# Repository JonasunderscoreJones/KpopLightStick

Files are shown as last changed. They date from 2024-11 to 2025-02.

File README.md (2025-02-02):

# K-Pop Lightstick
This Repo features the software of an Arduino Lightstick as well as the 3D Files for a custom **NCT DREAM** Lightstick

<div style="display: flex; justify-content: space-between">
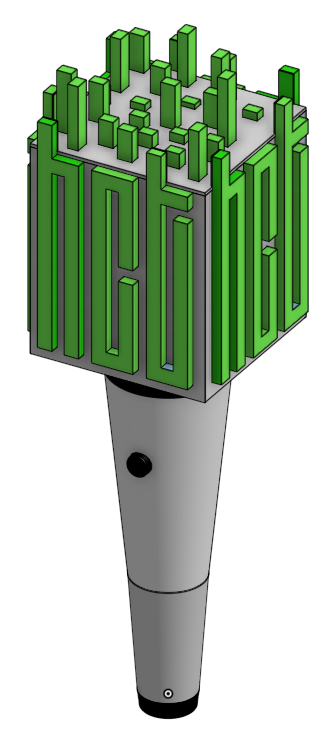
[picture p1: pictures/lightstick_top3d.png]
  
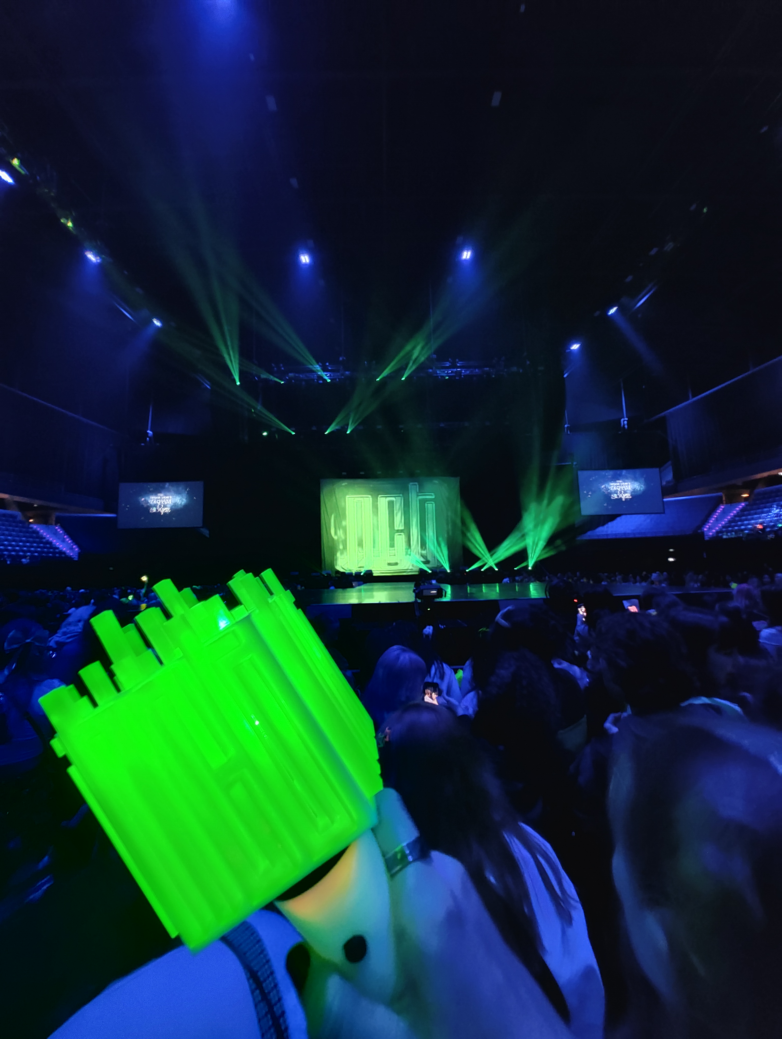
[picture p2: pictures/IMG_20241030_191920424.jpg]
  
</div>

## 3D-Print
The Lightstick was printed in 3 different colors.

The `Block Top.stl` file can be modified to not come with holes for the `Neo_City.stl` cubes rising out of the top to match the official lightstick more accurately.

*Be aware, that this 3D Build is slightly larger than the Official NCT DREAM Lightstick and you may not be allowed into concerts with it. I had no issues at the NCT DREAM Tour 2024 in Rotterdam but the security checks at the entrance were cursory, lacking the thoroughness you would usually have at different concerts.*

**WHITE:**
- `Block Base.stl`
- `Block Side.stl`
- `Block Top.stl`
- `Handle Base Bottom.stl`
- `Handle Base.stl`

**BLACK:**
- `Handle Ring Bottom`
- `Handle Ring Top`
- `Power Button`

**TRANSPARENT NEON GREEN:**
- `Neo_City.stl`
- `shiny_c_thicker.stl`
- `shiny_c.stl`
- `shiny_n_thicker.stl`
- `shiny_n.stl`
- `shiny_t_thicker.stl`
- `shiny_t.stl`

*Since I had issues with the prints of the letters, I made a thicker version of each letter to ensure that there would be no holes.*

## Assembly
The Assembly of the Prints is pretty self-explanatory. Take a look at the pictures in the `/picture` folder of the repo.

I chose to not glue the `Block Base.stl` and the `Handle Base.stl` pieces together to be able to troubleshoot/replace the electronics inside at any time.

## Electronics
The `arduino.ino` file contains the Arduino code I used for the lightstick.

An **Arduino Nano** was used with the following Pin-Out:
```cpp
const int buttonPin = 2; // Pin for the button
const int redPin = 11; // Pin for the red channel of RGB LED
const int greenPin = 10; // Pin for the green channel of RGB LED
const int bluePin = 9; // Pin for the blue channel of RGB LED
const int motorPin = 8; // Pin to control the motor
```
*Note: These are the Digital Pins on the Arduino Nano*

### Features of the Program
- The `buttonPin` is for the Power Button on the `Handle Base.stl` and is used for controlling the Light.
- The `redPin`, `greenPin` and `bluePin` are used for controlling the LED. IMPORTANT: These are **ANODE RGB LEDs**. If You plan on using *Kathode LEDs*, simply remove `255 - ` from the `setRGB` function at the bottom of the Program, to invert the values. (This is only a fix based on logic, I have no LEDs to test it)
- The `motorPin` is used for controlling a simple Vibration Motor that runs for 1 second when turning on the Lightstick. This is inspired from the *VIXX Official Lightstick* that has similar behaviour. It is completely irrelevant to the general functionality of the Lightstick which is, well, to have Light.

### Instructions
1. Connect a Power button to the Arduino `buttonPin` and groud
2. Connect the Vibration Motor (A simple motor with some weight glued off-axis to make it vibrate when rotating) to the `motorPin` and ground
3. Connect the RGB LEDs to the 3 color pins and 3.3V
4. Glue together 3 AAA Batteries, solder them together and connect them to the Voltage In` and ground
5. Flash the Arduino Nano with the program and you're done.
6. Insert the electronics into the Arduino and close it up. The batteries go into the `Handle Base Bottom.stl` that is simply forced into the `Handle Base.stl`. There is a locking mechanism like the Official Lightstick has but I have found it to not be necessary as the fit is tight enough.

## Usage
Hold the Power Button for approx. 1 second and release it. The Lightstick should vibrate for a second and then the lights turn on, defaulting to a neon green.

Press the button to cycle between colors and hold it for a second to turn it off again.

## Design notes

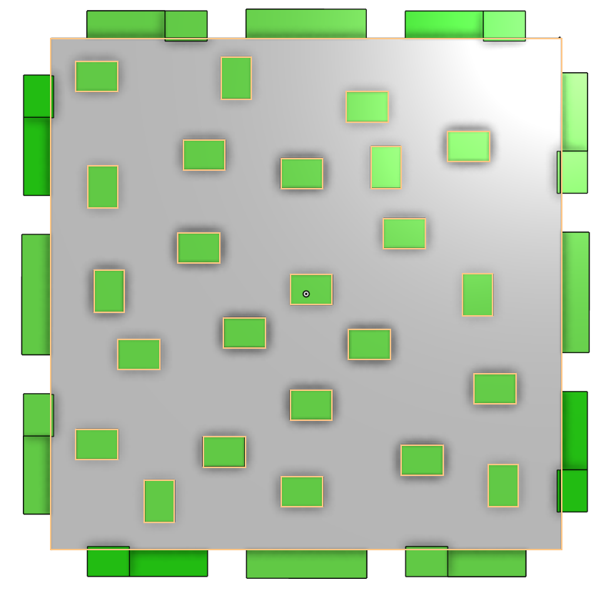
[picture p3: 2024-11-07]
pictures/lightstick_top.png

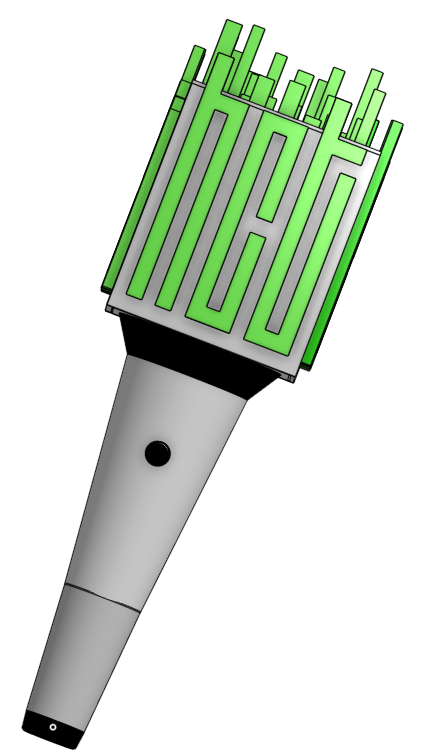
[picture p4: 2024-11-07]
pictures/lightstick_diagonal.png

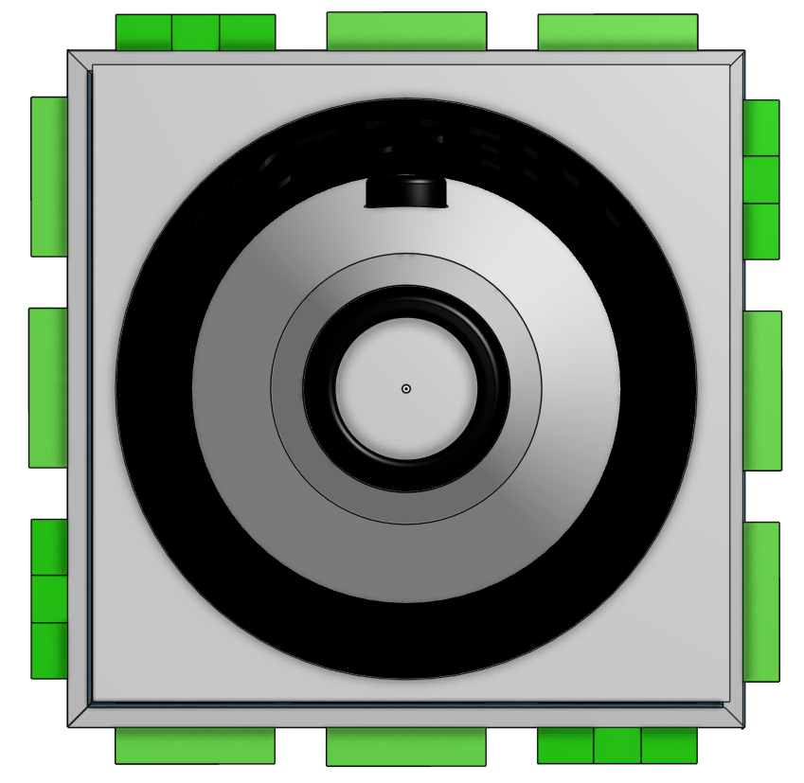
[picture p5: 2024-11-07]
pictures/lightstick_bottom.png

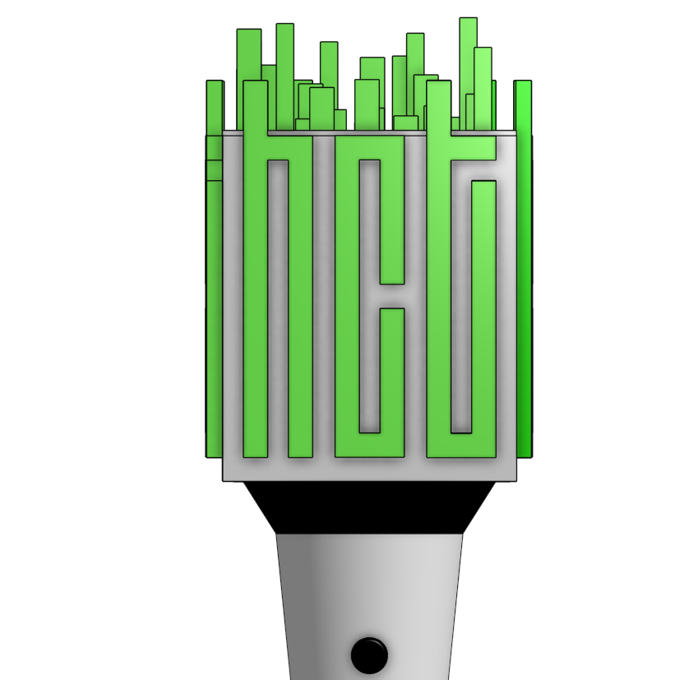
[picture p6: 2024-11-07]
pictures/lightstick_cube.png

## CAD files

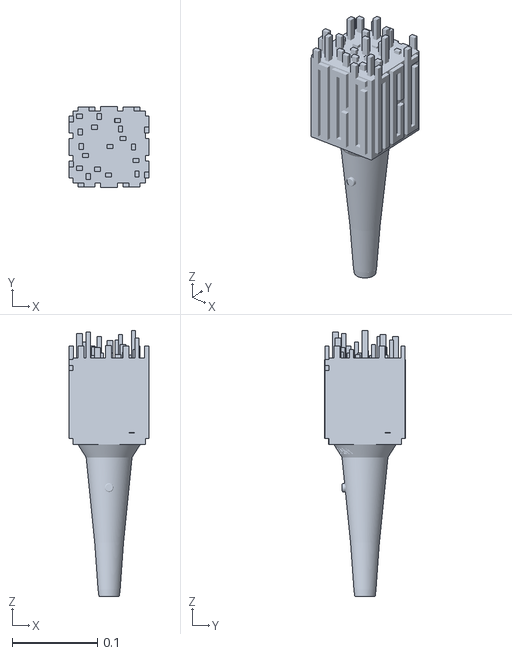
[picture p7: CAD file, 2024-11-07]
3d-files/assembly_complete.stl
0.0945 x 0.0946 x 0.313

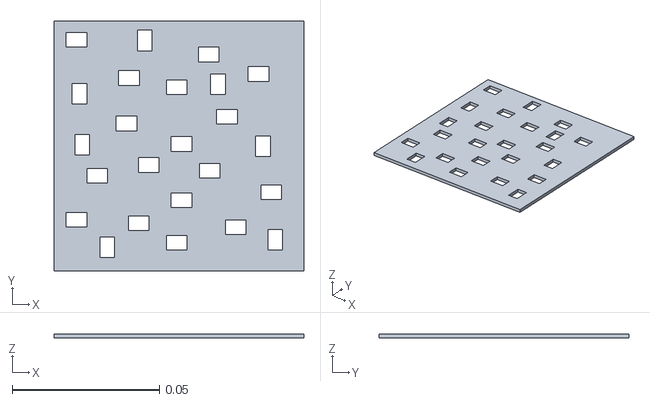
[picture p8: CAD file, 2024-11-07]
3d-files/Block Top.stl
0.085 x 0.085 x 0.0015

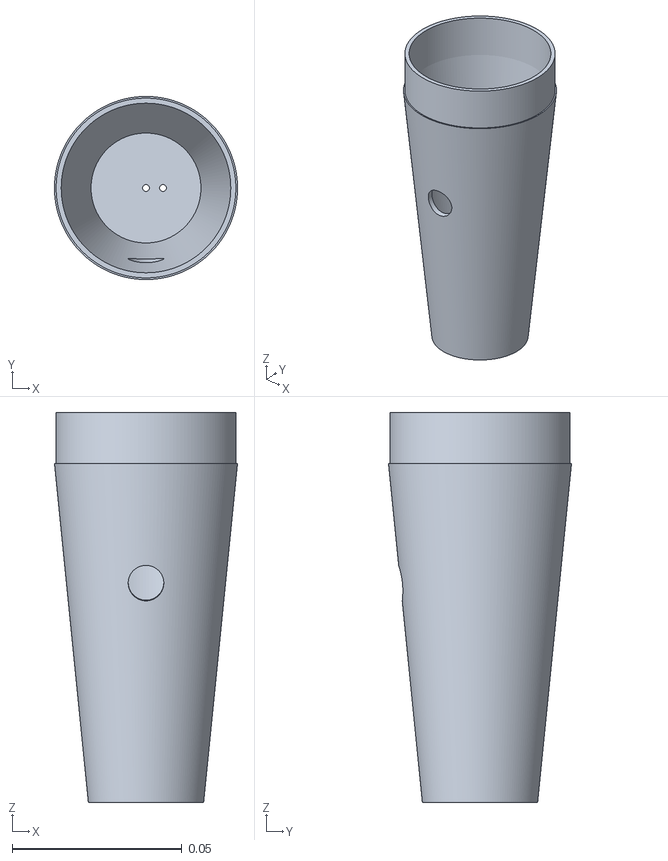
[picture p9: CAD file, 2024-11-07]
3d-files/Handle Base.stl
0.054 x 0.054 x 0.115

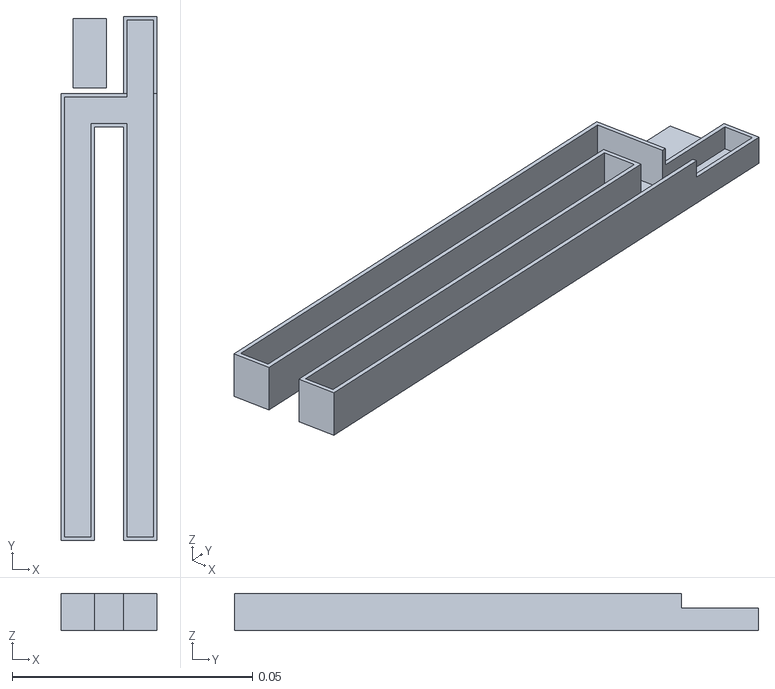
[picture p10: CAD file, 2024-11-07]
3d-files/shiny_n_thick.stl
0.02 x 0.109 x 0.00775

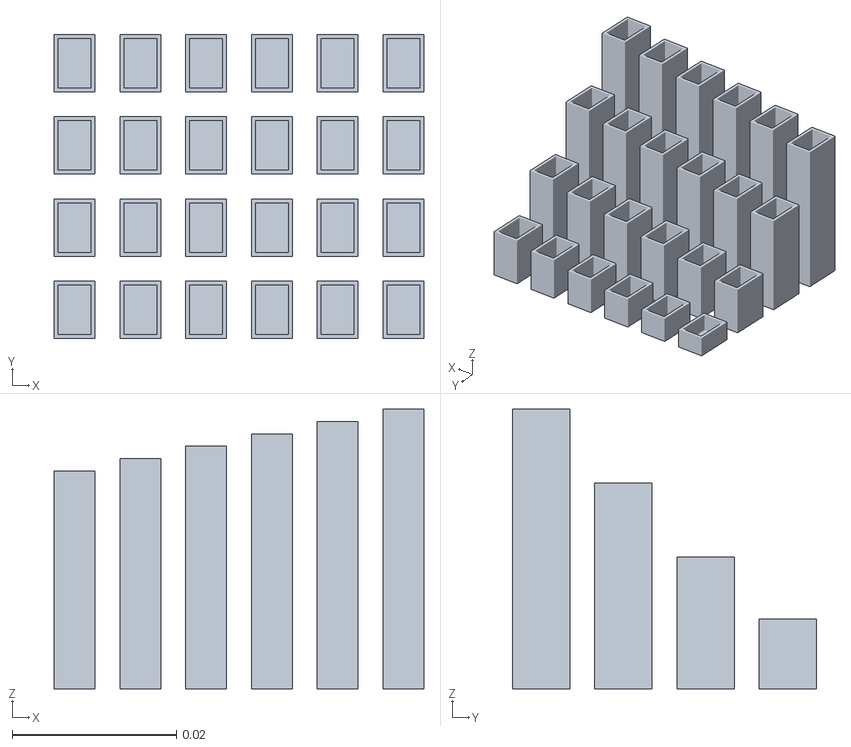
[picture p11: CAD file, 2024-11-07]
3d-files/Neo_City.stl
0.045 x 0.037 x 0.034

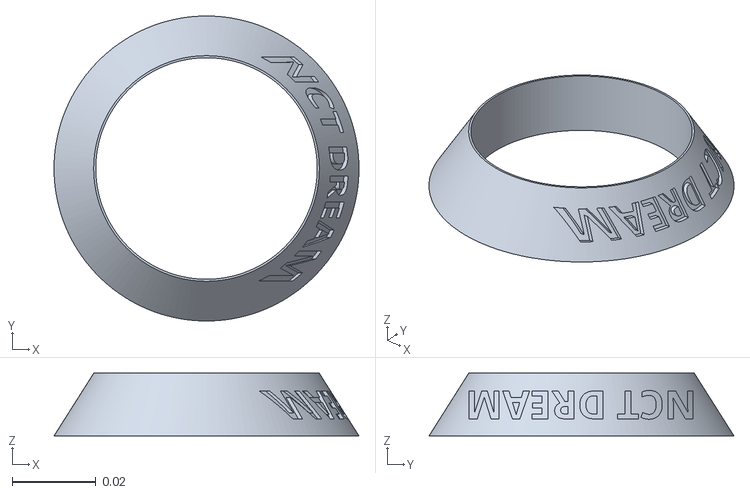
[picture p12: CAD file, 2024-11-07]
3d-files/Handle Ring Top.stl
0.073 x 0.073 x 0.015

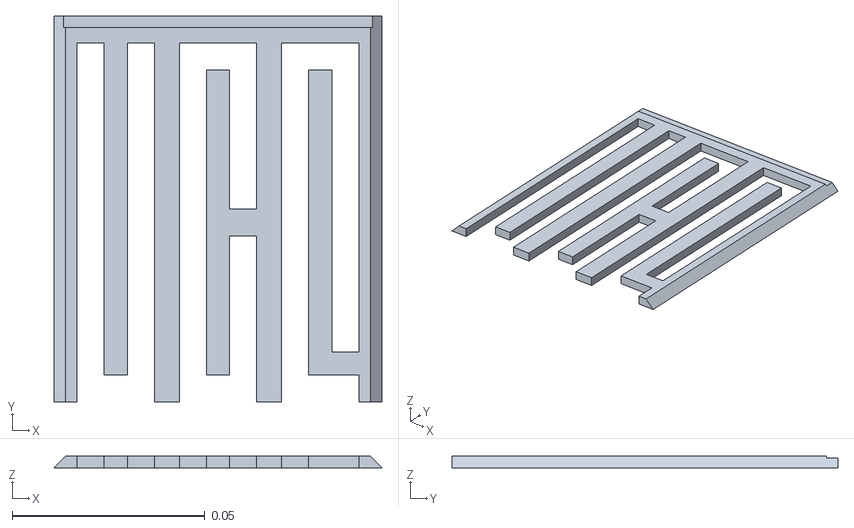
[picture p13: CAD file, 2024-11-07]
3d-files/Block Side.stl
0.085 x 0.1 x 0.003

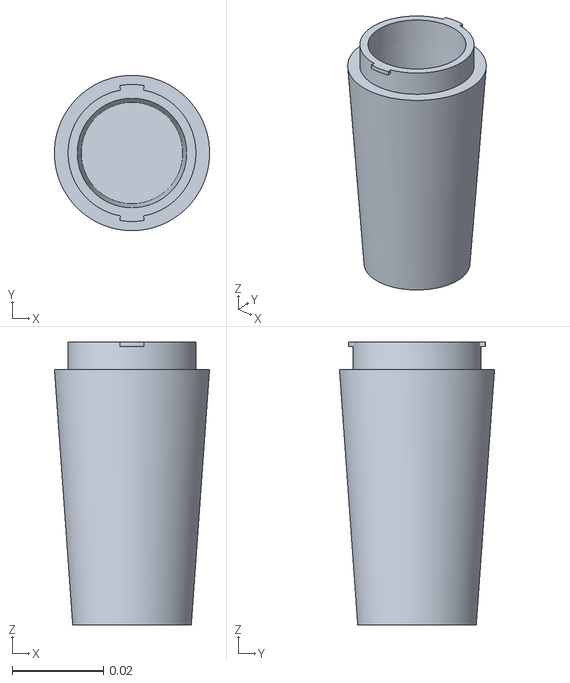
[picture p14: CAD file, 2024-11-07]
3d-files/Handle Base Bottom.stl
0.034 x 0.034 x 0.062

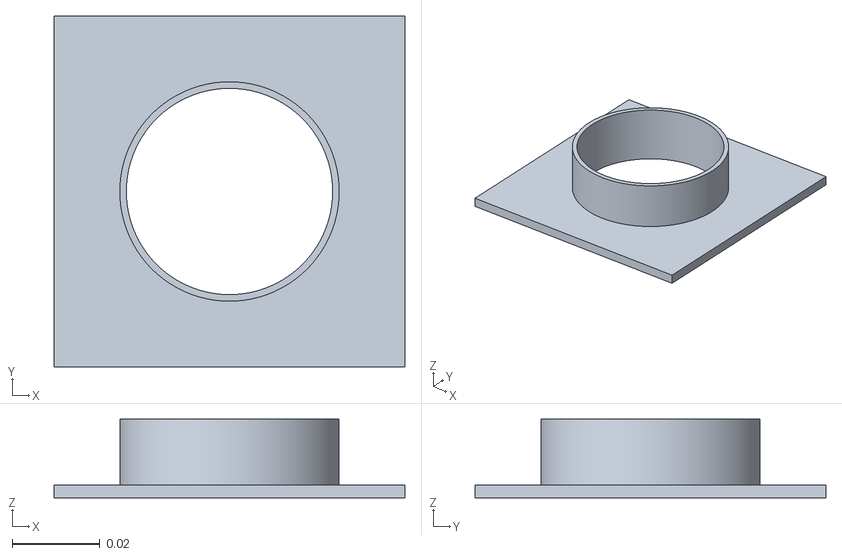
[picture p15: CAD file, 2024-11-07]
3d-files/Block Base.stl
0.08 x 0.08 x 0.018

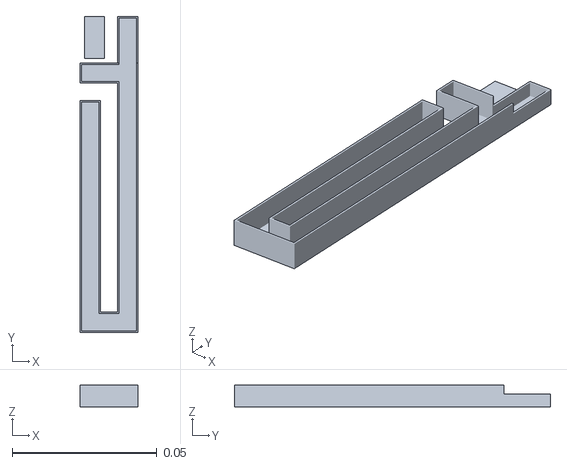
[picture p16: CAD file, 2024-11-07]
3d-files/shiny_t.stl
0.02 x 0.109 x 0.0075

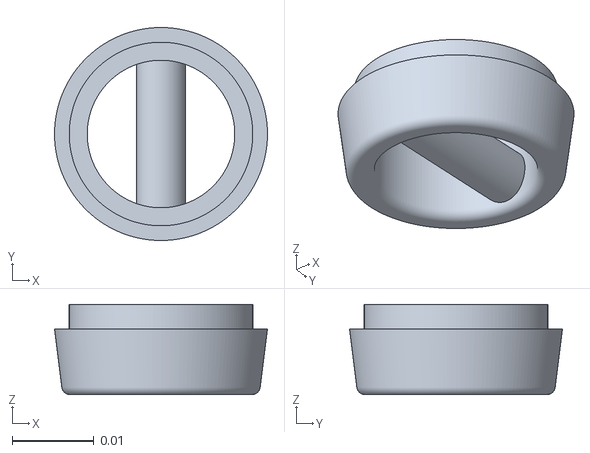
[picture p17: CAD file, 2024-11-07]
3d-files/Handle Ring Bottom.stl
0.026 x 0.026 x 0.011

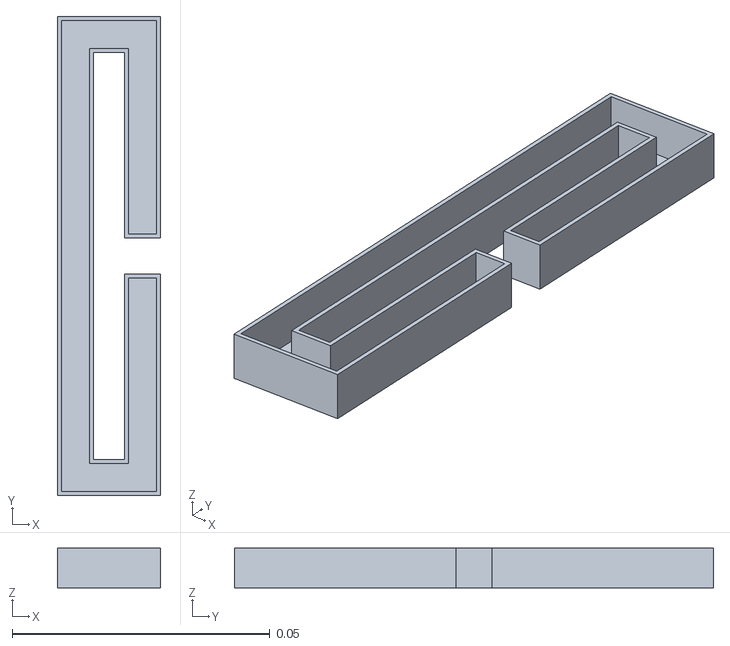
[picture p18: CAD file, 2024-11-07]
3d-files/shiny_c_thick.stl
0.02 x 0.093 x 0.00775

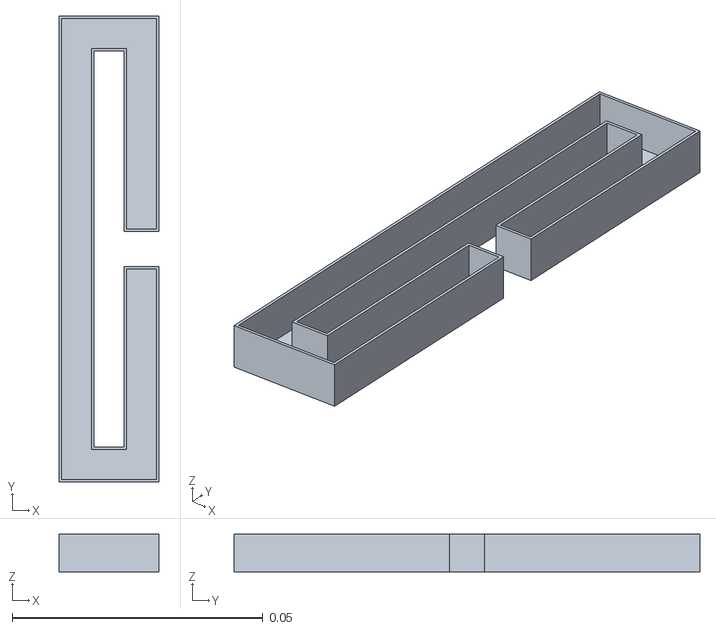
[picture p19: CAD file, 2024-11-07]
3d-files/shiny_c.stl
0.02 x 0.093 x 0.0075

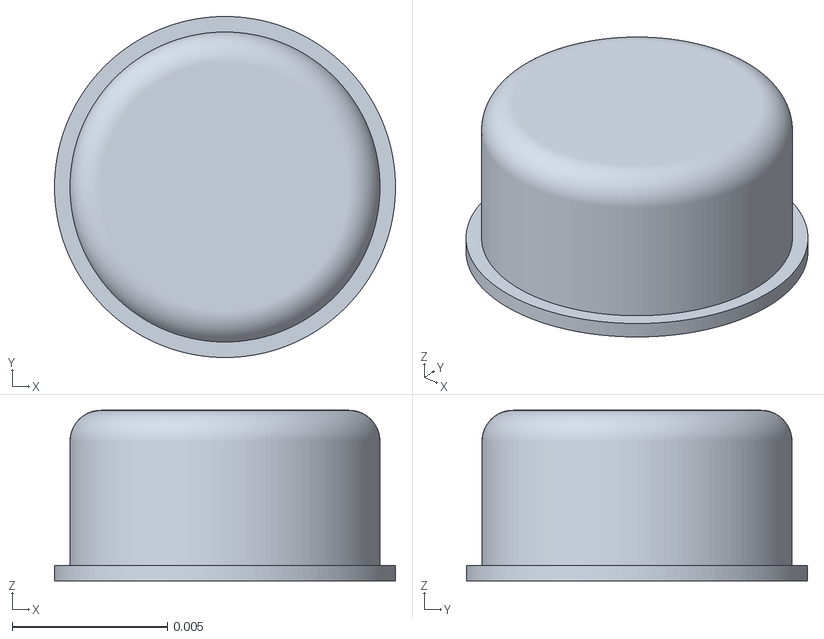
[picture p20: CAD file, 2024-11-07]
3d-files/Power Button.stl
0.011 x 0.011 x 0.0055

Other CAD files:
3d-files/shiny_t_thick.stl
3d-files/shiny_n.stl

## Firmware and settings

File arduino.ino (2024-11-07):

const int buttonPin = 2; // Pin for the button
const int redPin = 11; // Pin for the red channel of RGB LED
const int greenPin = 10; // Pin for the green channel of RGB LED
const int bluePin = 9; // Pin for the blue channel of RGB LED
const int motorPin = 8; // Pin to control the motor

bool ledState = false; // State of the onboard LED
unsigned long buttonPressStartTime = 0; // Time when the button press starts
bool buttonPressed = false; // Current button pressed state
unsigned long lastButtonPress = 0; // Last time the button was pressed
int colorIndex = 0; // Index for cycling colors

// Define colors to cycle through (RGB format)
const int colors[][3] = {
    {127,255,0},     // Neon Green
    {255, 0, 0},    // Red
    {0, 255, 0},    // Green
    {0, 0, 255},    // Blue
    {255, 255, 0},  // Yellow
    {0, 255, 255},  // Cyan
    {255, 0, 255}   // Magenta
};
const int numColors = sizeof(colors) / sizeof(colors[0]);

void setup() {
    pinMode(buttonPin, INPUT_PULLUP); // Set the button pin as input with pull-up resistor
    pinMode(ledPin, OUTPUT); // Set the LED pin as output
    pinMode(redPin, OUTPUT); // Set the red pin as output
    pinMode(greenPin, OUTPUT); // Set the green pin as output
    pinMode(bluePin, OUTPUT); // Set the blue pin as output
    pinMode(motorPin, OUTPUT); // Set the motor control pin as output

    // Initialize RGB LED to off and motor off
    setRGB(0, 0, 0);
    digitalWrite(motorPin, LOW); // Ensure motor is off

    pinMode(LED_BUILTIN, OUTPUT); // Set the onboard LED pin as an output
    digitalWrite(LED_BUILTIN, LOW); // Turn the LED off
}

void loop() {
    // Read the button state
    bool currentButtonState = digitalRead(buttonPin) == LOW;

    if (currentButtonState && !buttonPressed) {
        // Button just pressed
        buttonPressed = true;
        buttonPressStartTime = millis(); // Record the time of the button press
    } else if (!currentButtonState && buttonPressed) {
        // Button just released
        buttonPressed = false;

        // Check duration of button press
        unsigned long pressDuration = millis() - buttonPressStartTime;

        if (pressDuration >= 500) {
            // Long press: Toggle onboard LED and motor
            ledState = !ledState;
            digitalWrite(ledPin, ledState ? HIGH : LOW);

            if (ledState) {
                // Turn motor on
                digitalWrite(motorPin, HIGH);
                delay(1000); // Keep motor on for 1 second
                digitalWrite(motorPin, LOW); // Turn motor off
                setRGB(0, 255, 0); // Start with green
                colorIndex = 0; // Reset color index
            } else {
                // Turn off RGB LED
                setRGB(0, 0, 0);
            }
        } else {
            // Short press: Cycle colors
            if (ledState) {
                colorIndex = (colorIndex + 1) % numColors; // Cycle through colors
                setRGB(colors[colorIndex][0], colors[colorIndex][1], colors[colorIndex][2]);
            }
        }

        // Wait until the button is released before proceeding
        while (digitalRead(buttonPin) == LOW);
    }
}

// Function to set RGB LED color
void setRGB(int red, int green, int blue) {
    analogWrite(redPin, 255 - red);
    analogWrite(greenPin, 255 - green);
    analogWrite(bluePin, 255 - blue);
}
